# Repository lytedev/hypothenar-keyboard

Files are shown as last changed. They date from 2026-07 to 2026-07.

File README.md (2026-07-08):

# Hypothenar PCB

The v1 redesign — chip-direct nRF52840 module + I/O expanders, designed
for JLCPCB PCBA assembly. See `docs/v1-design.md` (in the repo root) for
architectural decisions and BOM rationale.

This directory is a work-in-progress. The PCB hasn't been drawn yet.

## Repositories

- **Primary**: <https://git.lyte.dev/lytedev/hypothenar-keyboard>
- **Mirror (GitHub)**: <https://github.com/lytedev/hypothenar-keyboard>
- **Sibling model**: [thenar](https://git.lyte.dev/lytedev/thenar-keyboard) — the hand-solderable original this design derives from ([GitHub mirror](https://github.com/lytedev/thenar-keyboard))

## What's here

- **`ref-designguide-schematic/`** — vendored copy of
  `ebastler/zmk-designguide` (CERN-OHL-P licensed). A reference schematic
  showing tested wireless-keyboard topologies: USB-C + ESD, TP4056 charge
  IC, XC6206 LDO, three different nRF52840 module options. This is our
  primary reference for the power tree and MCU section. Open
  `ref-designguide-schematic/designguide-schematic.kicad_sch` in KiCad
  to view.

- **`lib/kleeb/`** — vendored MIT-licensed KiCad library from
  `crides/kleeb`. The only public source of the **MS88SF3 nRF52840
  module footprint + symbol** (in `lib/kleeb/mcu.pretty/ms88sf3.kicad_mod`
  and the `mcu.kicad_sym` symbol library). Add this to KiCad's path when
  drawing the schematic.

- **`lib/marbastlib/`** — CERN-OHL-P keyboard-focused KiCad library by
  ebastler. Used by zmk-designguide. Contains symbols + footprints for
  TP4056, XC6206, USB-C connectors, etc.

3D models from both libraries are stripped (~88 MB saved). Re-fetch the
original repos if you want 3D viewer support.

## Project skeleton

Two KiCad projects ready to open:

```
kicad/hypothenar-left/
  hypothenar-left.kicad_pro    # start with: nix develop -c kicad
  hypothenar-left.kicad_sch    # currently == designguide schematic (verbatim copy)
  hypothenar-left.kicad_pcb    # empty, will populate from netlist later
  sym-lib-table               # project-local symbol library wiring
  fp-lib-table                # project-local footprint library wiring

kicad/hypothenar-right/
  hypothenar-right.{kicad_pro,kicad_sch,kicad_pcb,sym-lib-table,fp-lib-table}
```

Open either project file (`.kicad_pro`) in KiCad and the kleeb +
marbastlib libraries are wired up automatically — search the symbol
browser for `MS88SF3`, `TP4056`, `XC6206`, `USB_C` etc. and they're all
present.

## Roadmap

1. **Prune the designguide schematic** to just what we want:
   - Keep: USB-C input + ESD, TP4056 charge IC, XC6206 LDO, one MCU
     module slot, Vsense divider (for battery reporting)
   - Delete: the other two MCU modules (Holyiot and Moko — we use the
     third slot for our MS88SF3), the alternative BQ24075 charge IC,
     the LED underglow circuit, the battery protection (DW01A/FS8205)
     — optional, depends on whether we want belt-and-suspenders
   - Replace: the Ebyte E73 module footprint slot with MS88SF3
   - Save. ERC should drop from 409 to <50.

2. **Add the MCP23017 section** (not in designguide):
   - Two MCP23017 ICs per half, I²C-connected to the MCU
   - Address straps for 0x20 and 0x21
   - 4.7 kΩ I²C pull-ups
   - Reset line tied to MCU GPIO
   - Reference: `SolderedElectronics/IO-expander-MCP23017-breakout-hardware-design`

3. **Add the matrix section**: 28 switches per half. With switch-per-pin
   topology, each switch has one pin → GPIO pin on one of the MCP23017s,
   other pin → GND. No diodes.
   - Will eventually come from the ergogen scaffold (regenerated for v1
     without diodes); for now stub with a placeholder.

4. **Add the rest of the per-half peripherals**: scrollwheel encoder,
   Nice!View headers, slider switch, reset button.

5. **Run ERC clean** on the schematic.

6. **Layout in KiCad**: import netlist into the `.kicad_pcb`, place
   footprints in the chip area, then bring in the ergogen scaffold
   matrix and stitch the two together.

7. **Routing**: probably mostly by hand again (autoroute will hit
   similar plateaus as rc1).

8. **Generate**: gerbers + pick-place CSV + BOM CSV → submit to JLCPCB.

## Working on this branch

`v1` is a git branch off `main`. To work on v1:

```sh
jj edit v1                                       # check out v1 branch
jj new                                           # start a new commit
# ... edit files ...
jj describe -m "v1(...): what I changed"
jj git push --bookmark v1
```

`main` continues to be the validated rc1 design.

## License notes

This repository bundles work under three licenses that are
compatible with this project's MIT licence:

- `ref-designguide-schematic/` — CERN-OHL-P v2 (`ebastler/zmk-designguide`)
- `lib/kleeb/` — MIT (`crides/kleeb`)
- `lib/marbastlib/` — CERN-OHL-P v2 (`ebastler/marbastlib`)

Both CERN-OHL-P and MIT permit redistribution + modification. Attribution
preserved by keeping each library's original LICENSE file untouched.

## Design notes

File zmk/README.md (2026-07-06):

# Hypothenar firmware

ZMK firmware for the v1 PCBA build (MS88SF3 module + 2× MCP23017 per
half over I²C, switch-per-pin, no diodes).

## Status: skeleton

This is a starting point that compiles in principle, NOT a verified
working firmware. Several pin assignments are placeholders that must
be reconciled against the final PCB:

- **MS88SF3 pad-to-nRF52840 GPIO map** — confirm against the Minew
  datasheet, then update both `hypothenar-pinctrl.dtsi` AND
  `./ergogen/config.yaml` together so wiring matches the firmware.
- **I²C addresses** — `mcp_a` at `0x20`, `mcp_b` at `0x21` matches
  the address-strap wiring in the ergogen config. If you change those,
  update `hypothenar.dts`.
- **Battery voltage divider GPIO** — `vbatt` references `&gpio0 13`;
  the actual divider pin depends on which MS88SF3 pad is used.

The first physical board will need a debug pass to verify all of the
above before this firmware works end-to-end.

## Layout

```
zmk/
├── boards/arm/hypothenar/        # Custom Zephyr board for MS88SF3
│   ├── board.cmake
│   ├── Kconfig.board
│   ├── Kconfig.defconfig
│   ├── hypothenar.dts            # MCU + I²C + MCP23017 children
│   ├── hypothenar-pinctrl.dtsi   # Pin selections
│   ├── hypothenar.yaml           # Board metadata
│   └── hypothenar_defconfig
├── boards/shields/hypothenar/    # Keyboard shield
│   ├── Kconfig.shield
│   ├── Kconfig.defconfig
│   ├── hypothenar.dtsi           # kscan + transform + encoder
│   ├── hypothenar-layouts.dtsi   # Physical positions for Studio
│   ├── hypothenar_left.overlay   # Left half input-gpios list
│   ├── hypothenar_right.overlay  # Right half input-gpios list
│   └── hypothenar.keymap         # Default keymap
├── build.yaml
└── west.yml
```

## Build

```bash
# All-in-one (firmware + flash helper):
nix build .#firmware
nix run .#flash -- left
nix run .#flash -- right

# Or just one half:
nix build .#firmware-left
nix build .#firmware-right
```

The first build fetches Zephyr deps and fails with a hash mismatch.
Copy the hash from the failure message into `flake.nix` (the
`v1-firmware`'s `zephyrDepsHash`) and rebuild.

## Topology notes

Why switch-per-pin (no matrix, no diodes):

- 2× MCP23017 per half give 32 GPIOs; we use 28 of them.
- Each switch shorts a single MCP23017 pin to GND when pressed; the
  driver's internal pull-up keeps the line high otherwise.
- ZMK's `zmk,kscan-gpio-direct` driver polls the expanders over I²C.
- No charlieplexing, no row/column matrix, no diodes — simplest
  electrical topology, but the per-switch I/O cost is higher (32 pins
  vs ~12 for a traditional matrix).

Why this works on a battery-powered keyboard:

- MCP23017 quiescent current is ~1 µA, negligible vs the BLE radio.
- I²C bus is only polled when a switch state changes (interrupt-
  driven) — the MCP23017 INT pin can wake the MCU from sleep.

Caveat (future work): the current shield reads the expanders by
polling, not via the MCP23017's interrupt pin. For battery life that
matters; wire `INTA`/`INTB` of each expander to an MCU GPIO and add
an interrupt binding to the kscan node. See ZMK's docs on
`gpio-input-bind` for the pattern.

## ZMK Studio support

`hypothenar-layouts.dtsi` defines the physical layout for ZMK Studio so
you get a keymap visualizer. Positions come from the rc1 layout (same
key geometry) — verify the v1 PCB outline hasn't drifted before you
trust the visualization.

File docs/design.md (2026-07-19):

# Hypothenar design notes

This branch (`v1`) is a redesign of the prototype (rc1, on `main`) for
**pick-and-place assembly via JLCPCB**. The user-visible changes:

- **No Nice!Nano module** — discrete nRF52840 chip on the main PCB.
- **No diodes** — 2× MCP23017 I²C I/O expanders per half, switch-per-pin
  topology (each key wired directly to one expander GPIO).
- **Most components placed by JLCPCB PCBA**, only through-hole / mechanical
  parts (switches, hotswaps, encoder, slider, reset, battery wires)
  hand-soldered.

rc1 (current `main`) stays as the validated prototype reference.

## Architecture choices

### Drop reversibility — two separate PCB designs

rc1 used the corax-style reversible PCB (one design, flipped for the
other half, with jumpers selecting per-side wiring). That made sense
for hand-soldering: one PCB SKU, user solders the appropriate jumpers.

For v1 (PCBA), reversibility becomes a tax:

- JLCPCB places all populated footprints either way — paying for
  duplicate footprints or jumper bridges is wasted money.
- The schematic complexity (jumpers around the MCU, display, encoder)
  multiplies with each chip we add. Discrete nRF52840 + 2× MCP23017
  + USB-C + charge IC means a *lot* of new jumpers to design around.
- We can't even verify a reversible v1 design without spending the
  PCBA money up front.

**Plan: two PCB layouts emitted from one ergogen config.** Ergogen's
built-in `mirror` directive handles the geometry; we get `hypothenar-left`
and `hypothenar-right` as independent KiCad files. Each gets:

- Components placed for its specific half (MCU on the inner edge, etc.)
- Pure single-side routing (no mirror copper)
- Its own gerber + PCBA order at JLCPCB

Cost delta: separate designs are ~$50-80 more for the first PCBA run
(two design setups vs one), but save iteration time and unlock smaller
per-half boards. Net win after the first revision.

### MCU: MS88SF3 nRF52840 module (not bare chip)

**Revised from bare chip.** Use the Minew **MS88SF3-nRF52840** module
(LCSC `C20416747`, Extended). It's the nRF52840 + 32 MHz crystal +
32.768 kHz crystal + antenna + matching network + decoupling network
all in one pre-certified SMD package.

Why pick the module:

- **Same chip, same power**: ~1.5 µA System OFF, identical to bare
  nRF52840. ZMK upstream supports it as `nice_nano` or similar board.
- **Lower BOM complexity**: replaces ~10-15 discrete parts (two
  crystals, four crystal caps, RF matching components, antenna, two
  DCDC inductors).
- **Lower Extended-fee burden**: one Extended setup instead of
  separate fees for the nRF52840, antenna, and assorted RF passives.
- **Pre-certified for BLE**: saves the FCC certification work if this
  ever goes commercial. (Doesn't affect a personal-use build, but
  removes a future barrier.)
- **De-risked RF**: the hardest design risk in v1 was getting the
  antenna match and crystal layout right. The module eliminates both.

Trade-offs:
- Physical: ~18×10 mm vs the bare chip's 6×6 mm. Plenty of board space
  for our purpose.
- Slightly higher per-unit cost ($1-3) than the bare chip — paid back
  by the BOM/setup-fee savings.

No discrete crystals, no discrete antenna, no DCDC inductors. The
module exposes the nRF52840 GPIO pins as castellated edge pads.

### I/O expanders: 2× MCP23017 per half

- LCSC: **CONFLICT — resolve before ordering.** This line says `C9678`
  (Basic); the PCBA BOM table below says `C47023` (Extended). They
  disagree on both the part number and the JLC tier (which affects
  setup-fee cost). Verify the actual in-stock MCP23017-E/SO on LCSC and
  make both references match. 16 GPIOs each, 32 total per half, 28 used
  for keys + 4 spare.
- I²C address strap: 3 address pins → 8 possible addresses per bus.
  Use 2 different addresses for the 2 expanders. Both halves use the
  same addressing since the MCU is local to each half.
- Pull-up resistors: 4.7 kΩ on SDA/SCL.
- Reset: tie `RESET` to MCU GPIO so MCU can reset the expanders on
  boot.

**Why MCP23017 over PCA9555A**: PCA9555A's headline advantage is
~40 nA standby current vs MCP23017's ~1 µA. On a 110 mAh / 3.7 V
battery, 1 µA would take 12.5 years to drain — utterly negligible
compared to the BLE radio's bursty mA draws and the MCU's own
3-5 µA sleep current. MCP23017 has wider community use in the ZMK
ecosystem and better Zephyr driver support, so it's the safer pick.

### USB-C: standard 24-pin receptacle

- LCSC: `C165948` (Korean Hroparts; common JLC-stocked USB-C).
- ESD protection: USBLC6-2SC6 (`C7519`) for D+/D-.
- 5.1 kΩ resistors on CC1/CC2 for USB-C pull-down (signals "I'm a UFP
  needing power").

### Power path

- **Battery in**: LiPo 3.7V nominal, same `301230` as rc1.
- **Charge IC**: **TP4056** (LCSC `C382139`, Extended) — 100-1000 mA
  programmable charge, single-cell. Functionally equivalent to
  MCP73831 (which we'd otherwise use), cheaper. Set charge current to
  ~100 mA via 12 kΩ on the PROG pin (good rate for our 110 mAh
  battery; faster damages cell life).
- **Regulation**: Nordic nRF52840 can run directly from LiPo voltage
  via its built-in DCDC (1.7–5.5 V input range). No boost/buck needed
  for the MCU itself.
- **3.3V rail** for MCP23017 + Nice!View: **XC6206P332MR** LDO
  (`C5446`, **Basic tier**) fed from battery. 1-3 µA quiescent current
  (~10× lower than TLV70233's 31 µA — meaningful on a 110 mAh battery).
  Saves the Extended setup fee.
- **Slider switch**: Same C128955 cuts the battery feed to charge+MCU.
- **Charge LED**: optional, 1× 0603 LED + 1 kΩ resistor wired to
  MCP73831's STAT pin.

### SWD programming header

- **5 pads** on the down-side near the MCU: SWDIO, SWCLK, RST, GND, 3V3.
- 2.54 mm spacing in a single row, exposed copper (no header pins
  installed by default — clip-on or pogo probe).
- Used once per board to flash the Adafruit nRF52 bootloader. After
  that, USB drag-drop works exactly like the Nice!Nano.

### Bootloader flashing strategy

**Primary plan: JLCPCB Component Programming service**

JLCPCB will flash a `.hex` to the nRF52840 as part of PCBA. For our
2-board run that's ~$15-30 total: $8-25 setup + $0.50-1.50 per board.
Cheaper than buying our own programmer and saves the manual SWD step.

What we supply: Adafruit nRF52 bootloader hex from
<https://github.com/adafruit/Adafruit_nRF52_Bootloader> (use the
`nice_nano_v2` build — same chip layout from ZMK's perspective).

After the one-time bootloader flash, USB drag-drop works exactly like
the Nice!Nano: double-tap reset to enter bootloader, drop `.uf2` on
the mass-storage device.

**Fallback: DIY SWD via Pi Pico (`picoprobe`)**

Still expose the 5-pin SWD pads on the PCB so you can recover bricked
boards or reflash without re-ordering. With a Pi Pico flashed as
picoprobe (~$5):

```
openocd -f interface/cmsis-dap.cfg -f target/nrf52.cfg \
  -c "program adafruit_nrf52_bootloader.hex verify reset exit"
```

## ZMK shield changes

The shield needs a custom board definition (`nice_nano` board no longer
applies). Path: create `config/boards/arm/hypothenar/` as a custom Zephyr
board, then the shield references it. Includes:

- `hypothenar.dts` — MCU + power + connectivity (chosen flash partitions,
  USB, I²C, BLE)
- `hypothenar_defconfig` — Kconfig for the board
- `Kconfig.board` — board declaration
- `board.cmake` — flash/debug command wiring

The kscan changes from `kscan-gpio-matrix` to **`zmk,kscan-gpio-direct`**
with all 28 GPIOs listed explicitly (each one is a switch).

The I/O expanders need a Zephyr driver — `MCP230XX` (built into Zephyr).
Devicetree binding: declare each as an `i2c-bus` device, configure pin
modes via the driver. Then `gpio-keys` or `kscan-gpio-direct` references
the expander's GPIO controller via phandles.

## BOM at LCSC (PCBA-ready)

**Verified against JLCPCB's parts catalogue 2026-05-18.** The IC-heavy
parts of this BOM are all **Extended tier** — JLCPCB doesn't stock
keyboard-specific MCUs and ESD/USB-C/charge ICs as Basic. Expect ~$24
in one-time Extended setup fees on first order; subsequent orders
using the same parts are free.

Per half (multiply ×2 for the keyboard total). "B" = Basic, "E" = Extended.

| Designator | Part | LCSC | Tier | Notes |
|---|---|---|---|---|
| U1 | MS88SF3 nRF52840 module | **C20416747** | E | Pre-certified; includes antenna, crystals, RF matching, DCDC inductors |
| U2, U3 | MCP23017-E/SO I/O expander | C47023 | E | SOIC-28 (SOP variant) |
| U4 | TP4056 LiPo charge IC | **C382139** | E | Programmable charge current via PROG resistor |
| U5 | XC6206P332MR 3.3 V LDO | **C5446** | **B** | 1-3 µA Iq; replaces TLV70233 — Basic tier, biggest cost+power win |
| U6 | USBLC6-2SC6 USB ESD | C7519 | E | Optional — nRF52840 has integrated USB ESD diodes. Skip if BOM cost matters more than belt-and-suspenders. |
| J1 | TYPE-C-31-M-12 USB-C receptacle | C165948 | E | Hroparts |
| C1 | 4.7 µF X5R 0603 cap | C19666 | B | Bulk decoupling |
| C2–C8 | 100 nF X7R 0603 cap | C14663 | B | Local decoupling (one per IC + USB-C + battery) |
| C9, C10 | 10 µF X5R 0603 cap | (TBD) | B | Battery bulk + charge IC |
| R1, R2 | 4.7 kΩ 0603 | C23162 | B | I²C pull-ups |
| R3, R4 | 5.1 kΩ 0603 | C23186 | B | USB-C CC pull-downs |
| R5 | 12 kΩ 0603 | C25744 | B | TP4056 PROG (sets 100 mA charge) |
| R6, R7 | 1 kΩ 0603 | C21190 | B | Various |
| R8, R9 | 100 kΩ 0603 | C25803 | B | Reset pull-ups |
| D1 | 0805 red LED (status/charge) | C84256 | B | Connected to TP4056 STAT pins |

**Removed from BOM** (handled inside the MS88SF3 module): bare
nRF52840, 32 MHz crystal, 32.768 kHz crystal, four 22 pF crystal caps,
two 10 µH DCDC inductors, chip antenna. That's ~7 fewer parts to place
and ~3 fewer Extended setup fees.

**Verification corrections from my first pass** (in case I need to
re-do this with similar parts): all the original C-numbers I cited for
ICs were wrong — they pointed at unrelated resistors/ADCs/etc. The
numbers above are validated against JLCPCB's actual catalogue.

Through-hole / hand-soldered (unchanged from rc1):
- 28× Kailh Choc hotswap sockets (C5333465)
- 1× EVQWGD001 encoder
- 1× C128955 slider switch
- 1× 2-pin tactile reset
- 1× 5-pin Nice!View header (if displaying)
- 2× battery solder pads

**Rough cost per half (post-optimization)**: ~$10-18 in components +
Extended setup fee (~$15 one-time across the BOM thanks to the LDO
swap + module consolidation; ~$9 savings vs the unoptimized BOM) +
~$10-15 PCB + ~$25-40 PCBA labour. So roughly **$45-75 per half** for
the assembled board, plus the unchanged through-hole BOM.

Two designs (left + right) in the same JLCPCB order share the Extended
fees: total project cost roughly **$90-150** for both halves on first
order, ~$55-90 per pair on revisions.

Savings tally vs the original BOM:
- XC6206 LDO: -$3 Extended fee + -$0.17 piece price + ~10× lower Iq
- MS88SF3 module: -3 Extended fees (crystals, antenna, nRF52840) + -7
  parts to place + zero RF design risk
- TP4056 charge IC: -$0.28 piece price
- Skip USBLC6 (optional): -$3 Extended fee + -$0.25 piece price

If we skip USBLC6 (the nRF52840 has integrated USB ESD diodes), total
Extended fees drop to ~$12 and per-half BOM cost to ~$8-15.

## Layout/routing risks (in roughly increasing order of risk)

1. **Power decoupling placement** — well-known recipe in the nRF52840
   datasheet. Follow Nordic's reference layout.
2. **I²C bus routing** — keep traces short, 4.7 kΩ pull-ups, both
   expanders on same bus is fine.
3. **USB-C signal integrity** — D+/D- should be ~90 Ω differential. At
   USB 2.0 speeds and our short trace lengths it's forgiving.
4. **32 MHz crystal layout** — Nordic has strict guidelines (ground
   guard ring, exact load caps). Get this wrong and BLE may not start.
5. **2.45 GHz antenna match** — even with a chip antenna, the feed
   trace needs a ground-keepout zone of ~5×8 mm. Get this wrong and
   range/reliability suffers.
6. **DCDC inductor layout** — physically close to nRF52840's DCC pins
   with a short ground return.

## Roadmap

- [ ] Architectural spike: confirm I²C-based I/O expanders work with ZMK
      via `MCP230XX` driver (research existing builds).
- [ ] Schematic in KiCad (NOT ergogen — ergogen doesn't do schematics,
      and we need one for proper review).
- [ ] Footprint set: vet ceoloide / infused-kim libraries; supplement
      with custom footprints where needed.
- [ ] Ergogen config that emits the matrix layout + key positions, then
      manually overlay the chip / power / USB area in KiCad on top of
      the ergogen scaffold.
- [ ] First-pass PCB layout in KiCad. Order of design: place MCU + RF
      first, then power, then I²C bus, then key matrix wiring.
- [ ] Pick-place + BOM files via `kicad-cli pcb export pos --format csv`
      and `kicad-cli sch export bom`.
- [ ] Test PCBA order: 5 boards, 1 fully assembled, 4 bare for spares /
      iteration.

## Reference designs

Identified through targeted search; each contributes a different
piece of the v1 design.

### Primary reference: `Ladniy/jiran-ble-lite`

<https://github.com/Ladniy/jiran-ble-lite>

- **License**: CERN-OHL-P v2.0 (permissive open hardware — fork-friendly)
- **Architecture**: Holyiot-18010 nRF52840 module (different module
  than our MS88SF3 but same architectural approach — pre-certified RF
  module instead of bare chip), split ergo, traditional matrix
- **KiCad source**: confirmed `.kicad_sch` / `.kicad_pcb` / `.kicad_pro`
  in `pcb/jiran-ble-lite/`, with separate left/right schematic files
- **Maturity**: 300+ commits, v1.1.3 (Oct 2023)
- **What we take**: split-half mechanics, power tree topology, USB-C +
  charge IC layout, KiCad project structure
- **What we replace**: Holyiot footprint → MS88SF3, the matrix
  section (their diodes → our MCP23017 expanders)

### Symbol/footprint source: `crides/kleeb`

<https://github.com/crides/kleeb>

- MIT-licensed KiCad 6 symbol + footprint library
- **The only place I found with MS88SF3 symbols** (`ms88sf3-nrf52840`
  and `ms88sf3-nrf52840-split`)
- Pull symbol + footprint directly from this library

### Power-tree reference: `ebastler/zmk-designguide`

<https://github.com/ebastler/zmk-designguide>

- Reference schematics for three nRF52840 modules (including Holyiot)
- Power-tree patterns (LDO sizing, VDDH handling for nRF52840 DCDC)
- Cross-reference for ZMK board file structure
- Companion library: `ebastler/marbastlib` (symbols + footprints)

### JLCPCB PCBA-feasibility reference: `ebastler/cornholius`

<https://github.com/ebastler/cornholius>

- License: CC BY-NC-SA 4.0 (**non-commercial only**, fine for personal
  use but be aware if you ever sell)
- **Gerbers only** (no `.kicad_sch` — can't fork the layout) but the
  repo includes a BOM proven against JLCPCB's economic/standard PCBA
  parts list
- Use as a sanity check: "are the parts we picked actually
  PCBA-assembled in a known-working design?"

### MCP23017 reference: `SolderedElectronics/IO-expander-MCP23017-breakout-hardware-design`

- Reference schematic for the MCP23017 section (TAPR OHL licence)
- Standard configuration: I²C pull-ups, address straps, reset
- Combined with `ZMK PR #1567` (MCP23017 driver) for the firmware
  side

## Concrete forking plan

1. **Fork `jiran-ble-lite`** into our `v1` directory as the starting
   PCB project
2. **Swap the MCU footprint**: Holyiot 18010 → MS88SF3, using kleeb's
   library
3. **Adapt the power tree**: TLV70233 → XC6206 (per our BOM
   optimisation), MCP73831 → TP4056
4. **Add the MCP23017 section** (not present in jiran-ble-lite),
   using SolderedElectronics' reference + ZMK driver docs
5. **Replace the matrix** with our ergogen-scaffold output (modify
   the ergogen config to output two-half / non-reversible layouts)
6. **Test the BOM** against cornholius's JLCPCB-PCBA patterns
7. **Generate the gerbers + pick-place + BOM CSV**, submit to JLCPCB
   for first PCBA order

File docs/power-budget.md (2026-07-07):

# Power budget & battery-life estimate

Analytical estimate for the hypothenar's 110 mAh (301230) LiPo, built
from datasheet figures and ZMK community baselines. This is a
**prediction with error bars, not a measurement** — the free empirical
check is logging ZMK's BLE battery telemetry on real hardware over a
week (see "Validating" below).

Numbers marked *typ* are typical datasheet values; real silicon and
temperature spread them. Where a figure comes from community
measurement rather than a datasheet it is marked *(community)*.

## Always-on floor (everything idle, radio connected)

| Draw | Current (typ) | Source |
|---|---|---|
| nRF52840, BLE connected idle (30 ms conn. interval) | ~50–100 µA | *(community)* — [ZMK power profiler](https://zmk.dev/power-profiler) baseline for nice!nano-class nRF52840 boards |
| XC6206P332MR LDO quiescent | 1–3 µA | [Torex XC6206 datasheet](https://www.torexsemi.com/file/xc6206/XC6206.pdf), Iq typ 1 µA |
| MCP23017 standby × 2 | ~2 µA | [MCP23017 datasheet](https://ww1.microchip.com/downloads/en/DeviceDoc/20001952C.pdf), Icc standby 1 µA max each |
| TP4056 battery reverse leakage (no USB) | ~2 µA | TP4056 datasheet (NanJing TopPower; no stable URL — value from the commonly distributed datasheet, flagging accordingly) |
| Battery ADC divider | ~0 (switched) | Divider is behind the P0.05 enable GPIO; conducts only during samples |
| **Idle total** | **~60–110 µA** | |

## Deep sleep (ZMK soft-off / System OFF after idle timeout)

| Draw | Current (typ) | Source |
|---|---|---|
| nRF52840 System OFF, full RAM retention | ~1.5–3 µA | Nordic nRF52840 datasheet, "Current consumption" (docs.nordicsemi.com) |
| LDO + MCP23017 ×2 + TP4056 | ~5 µA | as above — these stay powered |
| **Sleep total** | **~7 µA** | |

Enabled via `CONFIG_ZMK_SLEEP=y` + 15-minute idle timeout in zmk/hypothenar.conf.

## The term that dominates: switch scanning

This design has no matrix — 28 switches sit behind two I²C expanders,
and `zmk,kscan-gpio-direct` reads them through the Zephyr MCP23xxx
driver. Two very different worlds:

- **Interrupt mode (what we wired)**: INTA of each expander → MCU GPIO
  (P0.30 / P0.02). Idle cost ≈ 0; each keypress costs a sub-ms I²C
  burst. At heavy typing (~5 keys/s) the scanning term averages
  **< 10 µA**. Rounding error.
- **Polling fallback (if interrupts were broken)**: reading both
  expanders every ~10 ms keeps the MCU + I²C bus duty-cycled
  continuously — order **300–500 µA average**, i.e. the battery dies
  in **~9–14 days** regardless of everything else. This is why the
  INT traces exist.

## Duty-cycle scenarios (interrupt mode)

Assume 16 h/day awake-and-connected, 8 h/day deep sleep:

| | mAh/day | 110 mAh lasts |
|---|---|---|
| Optimistic (60 µA idle, sleep works) | ~1.0 | **~3.5 months** |
| Central (90 µA idle) | ~1.5 | **~2.5 months** |
| Pessimistic (110 µA + no deep sleep, 24 h connected) | ~2.6 | **~6 weeks** |
| Polling fallback (broken interrupts) | ~8–12 | **~9–14 days** |
| Realistic 8 h/day active use + 15 h deep sleep | ~1.3 | **~2.5–3 months** |

Typing adds surprisingly little: connected-idle already pays the BLE
keep-alive tax, and active keystrokes only add ~50–150 µA *while
typing* (~5 µC per radio event at 10–20 events/s — estimate from BLE
event-charge math; the ZMK power profiler models the same). Battery
life is governed by **hours connected**, not keystrokes — a real
workday with aggressive sleep matches the 16 h-connected scenario.

The right half (peripheral) sits in the same band — its BLE peripheral
link to the central costs about the same as the central's dual role.

Adds if fitted: nice!view display ≈ +2–15 µA (Sharp memory LCD;
negligible). A rest-closed encoder contact against an internal ~13 kΩ
pull-up would cost ~250 µA — **verify at bring-up that the EVQWGD001's
detent-rest position leaves both contacts open**; if not, the pulls
need to be external and larger.

## Bottom line

**~2–3.5 months** per charge if the interrupt path works and deep
sleep is enabled; **~9–14 days** if scanning silently degrades to
polling. The gap between those two numbers is the entire reason the
INTA traces are on the board, and it is also the cheapest possible
test instrument: battery life in *weeks* = interrupts broken, in
*months* = working — readable from ZMK's own battery telemetry with
no bench equipment.

## Actions this analysis produced

- [x] Wire MCP23017 INTA → MCU (P0.30/P0.02) — done
- [x] Enable `CONFIG_ZMK_SLEEP=y` (+ idle timeout) — zmk/hypothenar.conf
- [ ] At bring-up: verify encoder rest-state contacts are open
- [ ] Validate: log BLE-reported battery % over a week of real use
      (upower on the connected host, 15-min samples); slope → real
      battery life. No PPK2 required.

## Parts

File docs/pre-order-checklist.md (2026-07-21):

# Pre-order checklist — the gate to a fab-ready PCBA

**Verdict as of this pass: NOT ready to order.** This board is a JLCPCB
pick-and-place run — SMD parts are baked in and cannot be reworked — and
it has **no schematic / no ERC**, so the ergogen nets are the only
netlist. This checklist is the gate: the board is "known ready to order"
only when every 🔴 item below is done and both halves pass a clean DRC.

Derived from the 2026-07 validation pass (netlist ERC cross-read +
`kicad-cli` DRC on `routed/keyboard-left.kicad_pcb` + BOM review).

> **⚠️ ARCHITECTURE CHANGED (2026-07): I2C expanders → diode matrix.**
> The 2× MCP23017 + I2C are gone; switches now scan as a direct diode
> matrix off the MS88SF3 (ergogen done + validated). This makes some
> items below stale — the routed boards are now doubly-outdated (the old
> layout AND the old architecture), so **both halves are a fresh route
> from the new scaffold.** Two new must-do items:
> - **Firmware kscan conversion** ✅ DONE — swapped to
>   `zmk,kscan-gpio-matrix` (6×12 transform, `diode-direction=col2row`) on
>   the verified pins; i2c/mcp nodes removed; encoder rotation fixed to
>   MCU P0.29/P0.28 (was the old mcp bug). **Builds clean both halves**
>   (`nix build .#firmware`). Two follow-ups, neither blocking:
>   *(a)* encoder **button** (ENC_SW=P0.13) still not scanned — it wasn't
>   before either; add via kscan-composite when wanted. *(b)* right-half
>   **column order** on the mirrored PCB is a bring-up-verify item (reverse
>   col-gpios in the right overlay if reversed — the thenar's bug class).
> - **BOM update** (part of item 4): remove the 2× MCP23017 + I2C
>   pull-ups/decoupling; add 28 diodes/half (Basic, e.g. 1N4148W / SOD-123)
>   — net *savings* (drops ~2 Extended setup fees).

---

## Done in this pass (source fixes)

- ✅ **MS88SF3 pad map datasheet-verified** (the foundational gate) — all
  assigned pads correct against Minew rev-K; see item 1 below.
- ✅ **Battery-sense divider resistors added** — R9 (820k, VBAT→BATT_ADC)
  + R10 (2.0M, BATT_ADC→BATT_ADC_EN), matching the firmware's divider
  (`output-ohms=2.0M`, `full-ohms=2.82M`). `BATT_ADC` was a floating
  single-pad net; now connected. *Verify R9/R10 placement on regen —
  shifts are near the MCU decoupling and may need nudging (a re-route is
  required anyway).*
- ✅ **Stale pin comment in `hypothenar.dts` deleted** — it listed
  `P14=USB_DP / P20=I2C_SCL / …`, which was wrong and would have
  sabotaged the datasheet cross-check.
- ✅ **BOM MCP23017 conflict flagged** — `C9678`/Basic (body) vs
  `C47023`/Extended (BOM table). Must be resolved (see 🔴 below).

## Verified GOOD (don't re-litigate)

- I²C bus: SDA=P0.26 / SCL=P0.27 match firmware; 4.7k pull-ups present;
  two MCP23017s at distinct 0x20 / 0x21.
- **Both INTA interrupt lines** wired and match firmware (P0.30 / P0.02)
  — the weeks-vs-months power factor is correct.
- Power tree: VBAT → TP4056 BAT / LDO VIN / MCU VDDH; PROG 12k → ~100 mA;
  CC pull-downs present; no power-net shorts.

---

## 🔴 Blocking requirements — must all be done before ordering

### 1. GATE — datasheet-verify the MS88SF3 pad map ✅ DONE (2026-07)
Cross-checked every assigned pad against the **Minew MS88SF3 rev-K
datasheet** (Datasheet_K_EN, §3 Pin Description diagram). **All correct,
pad-for-pad** — GND 1/18/34, VDD 31, VDDH 32, VBUS 35, D- 36, D+ 37,
SWDIO 49, SWCLK 50, and every GPIO (P9=P0.02, P10=P0.29, P11=P0.28,
P12=P0.30, P13=P0.31, P14=P0.27, P15=P0.05, P16=P0.04/AIN2, P17=P0.26,
P28=P0.18, P41=P0.17, P44=P0.20, P45=P0.22). Pads 33=DCCH / 51=RF
correctly NC. `config.yaml` + `hypothenar.dts` status updated. **Gate
cleared** — the netlist rests on a correct foundation.

### 2. Add the SWD + debug/expansion breakout header ✅ DONE (source)
`ergogen/footprints/breakout.js` + a `breakout` entry now expose **SWD
(SWDIO/SWCLK/RST) + power (3V3/GND/VBAT) + all 34 free nRF GPIOs** on a
2×20 header, auto-wired via net defaults (the 34 free MS88SF3 pads carry
`GP_*` nets that land on the header). Validated: ergogen regenerates,
KiCad loads it (J1), each `GP_*` net connects MCU-pad↔header-pad. This
kills the unprogrammable-brick blocker. **Remaining (yours, in KiCad):**
the 2×20 header is ~50×5 mm and a placeholder position — **relocate it to
open board space and trim pads/rows** to what fits ("start Max, shrink").
Its routing folds into item 3.

Original context (the matrix is entirely on the I²C expanders, so most
GPIOs are free):
- **SWD/bring-up (required):** SWDIO, SWCLK, RESET, GND, 3V3 (VDD_MCU).
- **Power taps:** VBAT, VBUS (optional).
- **Free GPIO expansion:** the pad map is now verified, so here is the
  full free-GPIO list (unused, real nRF52840 GPIOs). Pick as many as the
  header size allows:
  - **P0 free (18):** P0.00·pad25, P0.01·pad24, **P0.03·pad6 (AIN1 — the
    one free analog-capable pin)**, P0.06·21, P0.07·20, P0.08·27,
    P0.09·55, P0.10·56, P0.11·23, P0.13·39, P0.14·30, P0.15·40, P0.16·29,
    P0.19·38, P0.21·42, P0.23·43, P0.24·46, P0.25·48
  - **P1 free (16):** P1.00·47, P1.01·59, P1.02·52, P1.03·60, P1.04·53,
    P1.05·58, P1.06·54, P1.07·57, P1.08·22, P1.09·26, P1.10·4, P1.11·2,
    P1.12·3, P1.13·7, P1.14·5, P1.15·8
  - ~34 free GPIOs total — the matrix is entirely on the I²C expanders,
    so the MCU is wide open. Note P0.00/P0.01 (pads 24/25) are the LFXO
    pins; the module has no 32 kHz crystal (ZMK uses internal RC), so
    they're usable as GPIO — but if you ever want a real 32 kHz crystal,
    reserve them.
- Needs a header/test-pad footprint (model on `battery_pads.js`) + a
  placement on the board. *Can be implemented here — say which/how many
  free pins to break out and I'll add the footprint + nets.*

### 3. Finish routing — per half, to a clean DRC
The left half is a ~95% freerouting **baseline**, not a finished board;
the right half isn't routed at all.
- **Left (`routed/keyboard-left.kicad_pcb`):** fix **4 USB shorts**
  (`USB_DP/USB_DM/VBUS/GND` ring at the connector) and route the **8
  opens** (incl. `USB_DP` pad A6, thumb switch S27, several GND pads).
- **Right half:** route it (mirror/second layout) from the updated
  scaffold.
- Re-run `kicad-cli pcb drc` on **each** half → **0 errors, 0 unconnected
  items** is the gate (silk/text warnings are fine; relax copper-to-edge
  to JLC's 0.3 mm min or nudge the 5 offenders).

### 4. Footprints are hand-solder heritage — adapt them for pick-and-place
These footprints came from the thenar (hand-soldered, reversible board)
and haven't been adapted to a single-sided PnP run. Three findings, all
caught while eyeballing the board in KiCad:

- ✅ **USBLC6 pads were shorted** — 1.2 mm-tall pads on a 0.95 mm pitch
  overlapped 0.25 mm, merging pins 1-2-3 and 4-5-6 and shorting
  `USB_DP`/`GND`/`USB_DM`/`VBUS` (a dead VBUS→GND short). Width/height
  were transposed. **Fixed** → DRC shorts now zero. *(This also explains
  the 4 "freerouting" shorts we'd misdiagnosed on the routed board.)*
- ⬜ **Diodes are on the FRONT.** `diode.js` (ComboDiode) has no `side`
  param and emits pads on **both faces plus through-hole** — great for
  hand-solder flexibility, wrong for PnP. All 28 land on top, which
  would force **double-sided assembly** (a real cost adder). Needs a
  bottom-only SMD variant (drop the F.Cu SMD pads and the THT pads).
- ⬜ **CPL reports the wrong side for everything.** Footprints hardcode
  `(module … (layer F.Cu))` even when `side: B` correctly routes their
  *pads* to `B.Cu` (MS88SF3, TP4056, XC6206, USBLC6, passives). KiCad's
  CPL export reads the **footprint layer**, so JLC would be told to
  place bottom-side parts on **top** → mis-assembled board. Fix: make
  the module layer follow `${p.side}` in the affected footprints, then
  verify the CPL shows `bottom` for all SMD.

### 5. Resolve the BOM MCP23017 part number
Verify the in-stock LCSC part (`C9678` vs `C47023`) and tier, make the
`design.md` body and BOM table agree, and confirm **USBLC6** is a BOM row
(it's in the netlist but wasn't in the table rows checked).

---

## 🟡 Should-do (not strictly order-blocking)

- **Encoder is mis-wired in firmware, not hardware** — the PCB is fine
  (quadrature on MCU P0.29/P0.28, button on `mcp_b` GPA4). Firmware reads
  `mcp_b 4/5`, so as-is the encoder + its button are dead. Fix in
  firmware (no PCB change): set `hypothenar.dtsi` `a-gpios=<&gpio0 29 …>`,
  `b-gpios=<&gpio0 28 …>`, and add `mcp_b` GPA4 to the kscan + a keymap
  position for the button. Doesn't block the order.
- **USBLC6 footprint pinout** — eyeball the pad→pin map in KiCad once
  (shunt ESD on DP/DM/VBUS/GND); low risk, but unverifiable statically.
- **Charge-while-off** — the slider sits *before* the TP4056
  (`VBAT_SW → slider → VBAT → charger`), so **slider off = no charging**
  (same trap as the thenar). If you want off-but-charging, rearrange:
  cell always on the TP4056 BAT, slider as a load switch on VBAT→MCU.
  Design decision.
- **Nice!View SPI** defined in pinctrl but no `&spi0`/display node in the
  DTS — display won't drive until added (firmware-only, post-order OK).

---

## Definition of "known ready to order"

All four 🔴 done, i.e.:
1. MS88SF3 pad map datasheet-signed-off, `config.yaml` + `hypothenar.dts`
   in lockstep.
2. SWD + breakout header on the board.
3. **Both** halves route to **0 DRC errors + 0 unconnected**.
4. BOM part numbers verified in-stock, no conflicts, USBLC6 present.

Then: export gerbers + drills per half (`build-recipe.md` Stage 6–7),
upload to JLCPCB, order. The 🟡 items can trail (firmware/optional).

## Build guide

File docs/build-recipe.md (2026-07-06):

# Hypothenar build recipe

End-to-end recipe to take `./ergogen/config.yaml` from a scaffold to a
JLCPCB pick-and-place order. Read [`v1-design.md`](./v1-design.md) first
for the architecture rationale (MS88SF3 module, 2× MCP23017, MCU-on-PCB
power tree).

This is a working-style document — write down what worked, mark what
didn't, and skip steps you've already done. The `Verify` lines are
checks I (Claude) leave for myself when picking the work back up later;
treat them the same way you would.

## Tools you need

- KiCad 9 — `nix shell nixpkgs#kicad` or your system install
- ergogen 4.x — `nix shell nixpkgs#ergogen`
- freerouting v2.2.4 — built by this flake; `nix run .#freerouting -- --help`
- `nix build .#scaffold` for a fresh ergogen output

## Stage 0 — regenerate the scaffold

The scaffold is the source-of-truth for placement; if you change
`./ergogen/config.yaml`, redo it.

```bash
# Pure-nix build (cached):
nix build .#scaffold && ls result/

# Or in-place for iteration:
nix run nixpkgs#ergogen -- ./ergogen -o /tmp/hypothenar-scaffold
```

The output contains `pcbs/keyboard.kicad_pcb` (a fab-format kicad_pcb,
no traces). The flake's `v1-scaffold` derivation also upgrades it to
KiCad 9 format and writes a `.kicad_pro` next to it so the project
opens cleanly.

**Verify:**

```bash
grep '(module ' result/pcbs/keyboard.kicad_pcb \
  | awk '{print $2}' | sort | uniq -c
# Expect: 28 PG1350, 2 MCP23017, 1 each of MS88SF3, USB-C, USBLC6,
#         TP4056, XC6206, encoder, slider, reset, text, 4 Hole.
```

If a class is missing, the `pcbs.keyboard.footprints` block in
`config.yaml` references a tag that no point carries (see commit
`fix(./ergogen): scaffold places all components` — same trap).

## Stage 1 — open the project and set design rules

Open `result/pcbs/keyboard.kicad_pro` in KiCad. The scaffold is on
sheet `keyboard.kicad_pcb`; everything else (project file, schematic
stub if you want one) is up to you. We're routing-only — no schematic.

**Board stackup** (File → Board Setup → Board Stackup → Physical Stackup):
two-layer, 1.6 mm thickness, 1 oz copper. JLCPCB's default.

**Design rules** (File → Board Setup → Design Rules → Constraints):

| Setting | Value | Why |
| --- | --- | --- |
| Minimum clearance | 0.127 mm | JLCPCB 5/5 mil cheap tier. Cheaper if you go 6/6 = 0.15 mm. |
| Minimum track width | 0.127 mm | Same. |
| Minimum via size | 0.6 mm | JLCPCB minimum drill 0.3 mm; via annular ring at least 0.15 mm. |
| Minimum via drill | 0.3 mm | JLCPCB cheap tier. |
| Minimum hole-to-hole | 0.5 mm | JLCPCB requirement. |
| Copper-to-edge clearance  | 0.3 mm | Edge.Cuts safety margin. |

**Net classes** (File → Board Setup → Net Classes):

| Net class | Track width | Via dia/drill | Members |
| --- | --- | --- | --- |
| Default | 0.2 mm | 0.6 / 0.3 | everything else (signal, switch matrix) |
| Power | 0.4 mm | 0.8 / 0.4 | `VBUS`, `VBAT`, `VBAT_SW`, `VCC`, `GND` |
| USB | 0.25 mm | 0.6 / 0.3 | `USB_DP`, `USB_DM` (diff-pair-ish, see below) |

Power tracks at 0.4 mm carry ~1 A comfortably with negligible
temperature rise — well above any real load on this board.

## Stage 2 — push components to final positions

The scaffold drops every component along an arc tangent to the matrix.
That's a starting point, not a layout. Push them into the right
half-board zones:

```
+-------------------------------------+
| matrix (5x6) and thumb cluster      |
|                                     |
|  MCU              MCP_A   MCP_B    |
|  (MS88SF3)        (left)  (right)  |
|                                     |
|  USB-C (edge)     LDO    Charge IC |
|  ESD (close to USB-C)               |
+-------------------------------------+
       \---/
       slider + reset edge
```

Concrete placement rules:

1. **USB-C goes at the top edge of the board**, centered between the
   inner two columns of the matrix. Cable strain-relief is the most
   important constraint — put it at a board edge so the connector
   ground tabs can solder to a board cutout.
2. **MS88SF3 antenna keepout.** The antenna is on one short edge of
   the module (see Minew datasheet, pg. 4). Orient the module so the
   antenna edge faces *off the PCB or toward a board edge*, with no
   ground plane within 5 mm of the antenna and no copper at all
   within 2 mm. **This is the single most consequential placement
   decision** — getting it wrong tanks BLE range.
3. **MCP23017s** sit *between* the MCU and the keys they drive. MCP_A
   has the num + top row keys; MCP_B has home + bottom + mod + thumbs.
   Aim for short trace runs from each expander pin to its switch.
4. **USBLC6 ESD** sits between the USB-C connector and the MCU's USB
   pins. As close to the USB-C as practical. The two diodes inside
   only protect what's downstream of them.
5. **TP4056 charge IC + XC6206 LDO** sit next to the USB-C area. The
   LDO needs a 1 µF input cap and 1 µF output cap (the BOM has
   100 nF — add 1 µF locally during this stage, see Stage 3).
6. **Slider switch + reset button at the bottom edge** so they're
   accessible when the case is closed.

Use `Edit → Select All Footprints → Move` to grab the MCU cluster as a
group and slide it inside the board outline. The scaffold pushes it
*outside* the outline (top-right corner) because ergogen anchors are
keyed off the matrix corner; rip it inside.

**Verify:** `kicad-cli pcb export svg --output /tmp/check.svg result/...`
and visually scan for collisions / footprints outside the board edge.

## Stage 3 — schematic decoupling caps (added in PCB editor)

There's no schematic. Add the decoupling caps directly as PCB
footprints using `Place → Footprint`, pick the 0603 cap from the
KiCad library (`Capacitor_SMD:C_0603_1608Metric`), and assign nets in
the footprint properties.

Required caps (per Nordic reference):

| Designator | Value | Net (one side) | Net (other side) | Location |
| --- | --- | --- | --- | --- |
| C1 | 4.7 µF  | VBUS | GND | next to USB-C VBUS pin |
| C2 | 100 nF  | VBUS | GND | next to USB-C |
| C3 | 1 µF | VBAT | GND | TP4056 VBAT pin (BATT input bulk) |
| C4 | 1 µF | VBAT | GND | XC6206 input pin (LDO input bulk) |
| C5 | 1 µF | VCC | GND | XC6206 output pin (LDO output bulk) |
| C6 | 100 nF  | VCC | GND | MS88SF3 VDD pin (MCU decoupling) |
| C7 | 100 nF  | VCC | GND | MCP23017 #1 VDD pin |
| C8 | 100 nF  | VCC | GND | MCP23017 #2 VDD pin |

Each 100 nF cap must be **within 2 mm** of its IC's VDD pad. The 1 µF
and 4.7 µF bulk caps can be further away but should be on the same
copper pour.

Resistors (also place in PCB editor):

| Designator | Value | From | To | Notes |
| --- | --- | --- | --- | --- |
| R1 | 4.7 kΩ  | VCC | I2C_SCL | I²C pull-up |
| R2 | 4.7 kΩ  | VCC | I2C_SDA | I²C pull-up |
| R3 | 5.1 kΩ  | USB_CC1 | GND | UFP role pull-down |
| R4 | 5.1 kΩ  | USB_CC2 | GND | UFP role pull-down |
| R5 | 12 kΩ | TP_PROG | GND | sets TP4056 charge current ≈ 100 mA |
| R6 | 100 kΩ  | VCC | I2C_RESET | pull-up so MCP23017 doesn't reset spuriously |
| R7 | 100 kΩ  | VCC | RESET | MCU reset pull-up |
| R8 | 1 kΩ | CHARGE_*  | LED+ | charge-indicator LED current limit (optional) |

## Stage 4 — route the board

Two strategies. The rc1 hybrid approach (route critical nets by hand,
autoroute the rest) worked well — it produced 44 vias vs 102 starting
from autoroute-only. Repeat that here.

### 4a. Hand-route critical nets first

Do these by hand, in this order:

1. **USB-C D+ / D-**. Keep them as a tight pair (parallel, equal length
   if you can swing it). They run from USB-C through USBLC6 to the
   MCU's USB pins. The whole pair should be ≤ 30 mm total.
2. **Antenna keepout zone**. Skip if not using the bare-chip nRF52840
   — the MS88SF3's antenna is internal. But still: don't route ground
   pour inside the antenna keepout zone on the module datasheet.
3. **Crystal**. The MS88SF3 has internal crystals, nothing to route.
4. **Power tree**: USB-C VBUS → TP4056 IN → battery → slider → TP4056
   OUT → MCU VBAT input → LDO IN → LDO OUT → MCU VCC, MCP23017s. Use
   the `Power` net class so traces are 0.4 mm.
5. **I²C bus**. Two short traces (SCL, SDA) from MCU to both MCP23017
   expanders. Keep both expanders on the same bus; don't make a
   star — daisy-chain.

### 4b. Autoroute the rest with freerouting

The remaining nets are 28 switch-to-MCP23017 hookups (single-ended,
short, no constraints). Autoroute them:

```bash
# Save your in-progress PCB first.
nix run .#route -- result/pcbs/keyboard.kicad_pcb /tmp/hypothenar-routed.kicad_pcb

# Replace the working PCB with the autorouted one (after diffing!):
cp /tmp/hypothenar-routed.kicad_pcb routed/keyboard-left.kicad_pcb
```

`v1-route` runs freerouting v2.2.4 with the rc1 pass count (50) and
the freerouting config (in this repo at `scripts/freerouting.rules`).
Expected ~20 min runtime; expect ~90-95% routed. Remaining unrouted
nets are usually the I²C and power ones we already hand-routed —
verify and clean up.

**Verify** by opening the PCB in KiCad: PCB Editor → Inspect → DRC.
Fix all errors before going to gerbers.

## Stage 5 — fill GND zones

Both layers get a flood-fill GND pour. Place → Add Filled Zone →
F.Cu, net = GND, hatched fill, clearance 0.3 mm. Repeat on B.Cu.
Press B to fill.

This buys two things: shorter ground returns (every via to GND is a
direct connection to the pour, not a wire) and a slight bit of EMI
shielding.

## Stage 6 — export fabrication files

```bash
nix build .#gerbers && ls result/
# Produces gerbers + drill files + pick-place CSV + BOM CSV
```

The `v1-gerbers` derivation also runs DRC inside KiCad and fails the
build if any errors remain.

## Stage 7 — order at JLCPCB

1. Upload `result/v1-keyboard-left.zip` (gerbers + drills) to JLCPCB.
2. Quantity: 5 (cheapest tier; you'll use 1, keep spares).
3. PCBA: yes, top side, standard tier.
4. Upload `result/v1-keyboard-left-bom.csv` and
   `result/v1-keyboard-left-cpl.csv` (pick-place).
5. Add Component Programming service (one-time setup) with the
   bootloader hex from
   `https://github.com/adafruit/Adafruit_nRF52_Bootloader/releases`
   (pick the `nice_nano_v2` build).
6. Repeat for the right half.

First order pays the Extended part setup fees (~$24); subsequent
revisions are free.

## Stage 8 — receive boards, smoke test

When the boards arrive:

1. Visual inspection: no shorts on the MCU pads, USB-C aligned, no
   tombstoned passives.
2. Power-only test: plug USB-C, check VCC = 3.3 V at the MCU pin
   (probe a cap, not the pad — easier).
3. Bootloader sanity: double-tap reset, expect `NICENANO` to appear
   as a mass-storage device. If it does, JLCPCB's bootloader flash
   worked.
4. ZMK firmware: `nix run .#flash -- left` (after Stage 9).

## Stage 9 — firmware build

See [`zmk/README.md`](../zmk/README.md). The short version:

```bash
nix build .#firmware-left
nix build .#firmware-right
nix run .#flash -- left
```

## Known traps

Things I'd like future-me to remember:

- **The MCU cluster anchors outside the board outline.** Move it inside
  before routing — `config.yaml` puts it where the matrix outline ends,
  not where it'd fit on the board. The fix is in `config.yaml` not
  KiCad; eventually rewrite the anchor as relative to `matrix_inner_home`
  with a smaller shift.
- **`undefined` pad nets are silent bugs.** If a footprint param has a
  plain string default (not `{ type: 'net', value: 'X' }`), the PCB
  emits `undefined` as the net spec and KiCad refuses to load. Always
  net-type your defaults.
- **`(fp_text user "${REFERENCE}")` from KiCad is hostile to JS template
  literals.** The converter escapes those; if you copy-paste from a
  fresh kicad_mod, escape `${` to `\${` manually.
- **Tags, not zone names, in `where:`.** A `pcbs.footprints.X.where: <zone>`
  doesn't auto-match — give each zone a unique tag if you want to
  target it.

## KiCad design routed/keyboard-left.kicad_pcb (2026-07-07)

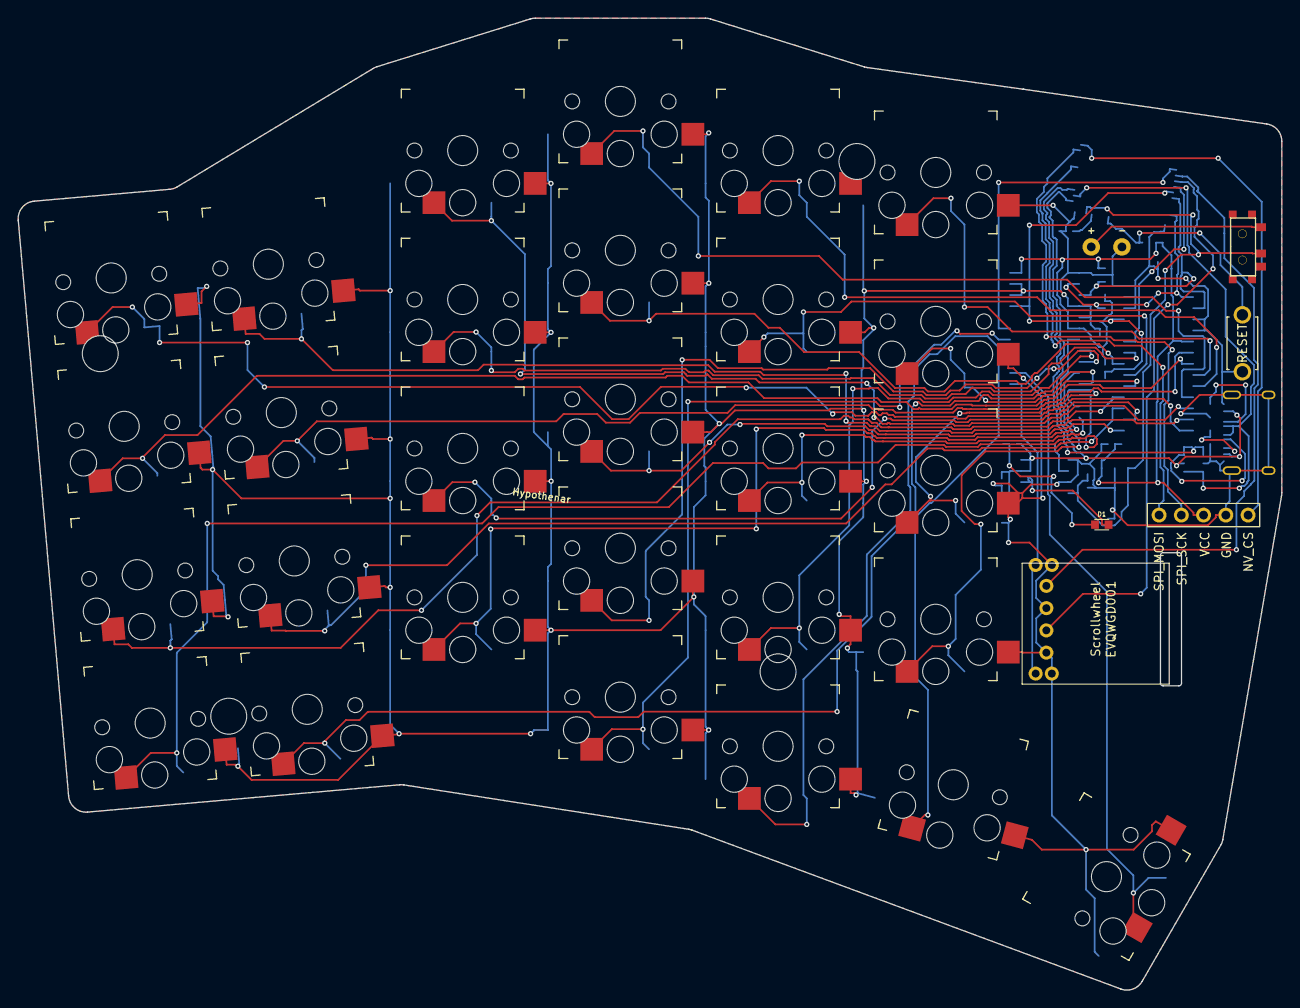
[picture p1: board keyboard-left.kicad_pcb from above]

Board: 2 copper layers, 144.2 x 110.9 mm, 60 parts (0 on the bottom side), 50 nets.

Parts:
19.051: ms88sf3
19.052, 19.053: MCP23017; MCP23017_SOIC-28W
19.054: USB_C_Receptacle_HRO_TYPE-C-31-M-12
19.055: USBLC6-2SC6; USBLC6-2SC6_SOT-23-6
19.056: TP4056; TP4056_SOP-8
19.057: XC6206P332MR; XC6206_SOT-89-3
BT1: BATTERY; battery_pads
DISP1: display_nice_view
P1: C1; passive_0603
P2: C2; passive_0603
P3: C3; passive_0603
P4: C4; passive_0603
P5: C5; passive_0603
P6: C6; passive_0603
P7: C7; passive_0603
P8: C8; passive_0603
P9: R1; passive_0603
P10: R2; passive_0603
P11: R3; passive_0603
P12: R4; passive_0603
P13: R5; passive_0603
P14: R6; passive_0603
P15: R7; passive_0603
P16: R8; passive_0603
P17: D1; passive_0603
S1, S2, S3, S4, S5, S6, S7, S8, S9, S10, S11, S12, S13, S14, S15, S16, S17, S18, S19, S20, S21, S22, S23, S24, S25, S26, S27, S28: PG1350
T1: SPDT_C128955
_1: ResetSW
_2, _3, _4, _5: Hole

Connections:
CHARGE_ACTIVE: 19.056.6, P17.2
CHG_LED: P16.2, P17.1
GND: 19.051.1, 19.051.18, 19.051.34, 19.052.10, 19.052.11, 19.052.14, 19.052.15, 19.052.16, 19.052.17, 19.053.10, 19.053.11, 19.053.14, 19.053.16, 19.053.17, 19.054.A1, 19.054.A12, 19.054.B1, 19.054.B12, 19.054.SH, 19.055.2, 19.056.1, 19.056.3, 19.057.2, BT1.2, DISP1.4, P1.2, P2.2, P3.2, P4.2, P5.2, P6.2, P7.2, P8.2, P11.2, P12.2, P13.2, S1.2, S2.2, S3.2, S4.2, S5.2, S6.2, S7.2, S8.2, S9.2, S10.2, S11.2, S12.2, S13.2, S14.2, S15.2, S16.2, S17.2, S18.2, S19.2, S20.2, S21.2, S22.2, S23.2, S24.2, S25.2, S26.2, S27.2, S28.2, _1.2
I2C_RESET: 19.051.13, 19.052.18, 19.053.18, P14.2
I2C_SCL: 19.051.14, 19.052.12, 19.053.12, P9.2
I2C_SDA: 19.051.17, 19.052.13, 19.053.13, P10.2
MCP_A_INT: 19.051.12, 19.052.20
MCP_B_INT: 19.051.9, 19.053.20
NV_CS: 19.051.45, DISP1.5
PROG: 19.056.2, P13.1
RESET: 19.051.28, P15.2, _1.1
SPI_MOSI: 19.051.41, DISP1.1
SPI_SCK: 19.051.44, DISP1.2
USB_CC1: 19.054.A5, P11.1
USB_CC2: 19.054.B5, P12.1
USB_DM: 19.051.36, 19.054.A7, 19.054.B7, 19.055.3, 19.055.4
USB_DP: 19.051.37, 19.054.A6, 19.054.B6, 19.055.1, 19.055.6
VBAT: 19.051.32, 19.056.4, 19.057.1, P3.1, P4.1, T1.2
VBAT_SW: BT1.1, T1.1
VBUS: 19.051.35, 19.054.A4, 19.054.A9, 19.054.B4, 19.054.B9, 19.055.5, 19.056.7, 19.056.8, P1.1, P2.1, P16.1
VCC: 19.052.9, 19.053.9, 19.053.15, 19.057.3, DISP1.3, P5.1, P7.1, P8.1, P9.1, P10.1, P14.1, P15.1
VDD_MCU: 19.051.31, P6.1
sw_matrix_index_bottom: 19.053.7, S19.1
sw_matrix_index_home: 19.053.1, S20.1
sw_matrix_index_mod: 19.053.22, S18.1
sw_matrix_index_num: 19.052.5, S22.1
sw_matrix_index_top: 19.052.23, S21.1
sw_matrix_inner_bottom: 19.053.8, S23.1
sw_matrix_inner_home: 19.053.2, S24.1
sw_matrix_inner_num: 19.052.6, S26.1
sw_matrix_inner_top: 19.052.24, S25.1
sw_matrix_middle_bottom: 19.053.6, S14.1
sw_matrix_middle_home: 19.052.28, S15.1
sw_matrix_middle_mod: 19.053.21, S13.1
sw_matrix_middle_num: 19.052.4, S17.1
sw_matrix_middle_top: 19.052.22, S16.1
sw_matrix_outer_bottom: 19.053.3, S1.1
sw_matrix_outer_home: 19.052.25, S2.1
sw_matrix_outer_num: 19.052.1, S4.1
sw_matrix_outer_top: 19.052.7, S3.1
sw_matrix_pinky_bottom: 19.053.4, S5.1
sw_matrix_pinky_home: 19.052.26, S6.1
sw_matrix_pinky_num: 19.052.2, S8.1
sw_matrix_pinky_top: 19.052.8, S7.1
sw_matrix_ring_bottom: 19.053.5, S9.1
sw_matrix_ring_home: 19.052.27, S10.1
sw_matrix_ring_num: 19.052.3, S12.1
sw_matrix_ring_top: 19.052.21, S11.1
sw_thumbs_layer_cluster: 19.053.23, S27.1
sw_thumbs_space_cluster: 19.053.24, S28.1

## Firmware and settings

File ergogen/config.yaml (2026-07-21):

# Hypothenar - chip-direct PCBA design.
#
# Architecturally different from rc1:
#   - Discrete nRF52840 module (MS88SF3) on the PCB, not a Nice!Nano daughter board.
#   - Diode matrix scanned directly by the MS88SF3 (converted from 2x
#     MCP23017 I/O expanders 2026-07 - the module has plenty of GPIOs).
#   - Switch-per-pin (each key directly wired to a unique GPIO) - no diodes.
#   - One PCB design per half (no reversibility; v1 emits this config twice
#     with mirroring for the right half).
#
# Status: MS88SF3 PAD MAP VALIDATED (2026-07) against the Minew MS88SF3
# rev-K datasheet (Datasheet_K_EN, section 3 Pin Description diagram) -
# every assigned pad (GND 1/18/34, VDD 31, VDDH 32, VBUS 35, D- 36, D+ 37,
# SWDIO 49, SWCLK 50, and GPIOs P9=P0.02, P10=P0.29, P11=P0.28, P12=P0.30,
# P13=P0.31, P14=P0.27, P15=P0.05, P16=P0.04/AIN2, P17=P0.26, P28=P0.18,
# P41=P0.17, P44=P0.20, P45=P0.22) matches the datasheet pad-for-pad.
# NOTE: pad 33=DCCH (DC/DC out) and 51=RF are correctly left NC (module
# handles DC/DC + antenna internally); pads 24/25=P0.00/P0.01 are the
# LFXO pins - the module has no 32.768kHz crystal, so ZMK runs the
# internal RC (fine for BLE). Component positions in the MCU/power zone
# are still first-pass; expect to iterate placement in KiCad.

units:
  kx: cx
  ky: cy
  px: kx+2
  py: ky+2
  # MCU module: MS88SF3 is 12.5 x 18.5 mm (kleeb footprint extents)
  mcu_width: 13
  mcu_height: 19
  # I/O expander: MCP23017 in SOIC-28W is ~10 x 18 mm including pads
  mcp_width: 10
  mcp_height: 19
  # USB-C: ~9 x 7.5 mm
  usbc_width: 10
  usbc_height: 8
  # Power chips smaller: TP4056 5x4, XC6206 4x2.5, USBLC6 3x2
  # General spacing
  mcu_padding: 1.5
  switchplate_switch_cutout: 14
  scrollwheel_width: 17
  scrollwheel_height: 14
  screw_diameter: 4.7
  screw_hole: 4.1

points:
  rotate: 5
  zones:
    # === Matrix: 5 rows x 6 cols, same physical layout as rc1's `thenar/`.
    # Each key gets a unique `switch_net` (not a matrix col_net/row_net) so
    # we can wire each switch to a dedicated MCP23017 GPIO.
    matrix:
      anchor.shift: [50, -150]
      key:
        tags: [switch]
        padding: 1ky
        spread: 1kx
      columns:
        outer:
          rows:
            mod.skip: true
          key:
            column_net: col0     # diode matrix: per-column driver net
        pinky:
          rows:
            mod.skip: true
          key:
            origin: [0, 8]
            column_net: col1
        ring:
          rows:
            mod.skip: true
          key:
            origin: [0, 8]
            stagger: 0.66ky
            splay: -5
            column_net: col2
        middle:
          key:
            stagger: 0.33ky
            column_net: col3
        index:
          key:
            stagger: -0.33ky
            column_net: col4
        inner:
          rows:
            mod.skip: true
          key:
            stagger: -2.5
            column_net: col5
      rows:
        # The `row_net` ergogen assigns to each row would normally be the
        # column-driver wire. In switch-per-pin we override per-key with
        # a unique net via the `from`/`to` params on the choc footprint -
        # see the pcbs.footprints section below.
        mod:    { row_net: __mod__,    tags: [switch_bottom] }
        bottom: { row_net: __bottom__, tags: [switch_top] }
        home:   { row_net: __home__,   tags: [switch_bottom] }
        top:    { row_net: __top__,    tags: [switch_top] }
        num:    { row_net: __num__,    tags: [switch_bottom] }

    # === Thumb cluster
    thumbs:
      anchor:
        ref: matrix_middle_home
        shift: [38, -44]
      key:
        tags: [switch]
        padding: 1ky
        spread: 1kx
      columns:
        layer:
          key:
            splay: -15
            column_net: col3    # diode matrix: __thumb__ row x col3
            tags: [switch_bottom]   # so it gets a diode (diode_bottom)
        space:
          key:
            width: 1.5kx
            splay: 75
            shift: [13-kx, -3]
            column_net: col4    # diode matrix: __thumb__ row x col4
            tags: [switch_space]
      rows:
        cluster:
          row_net: __thumb__

    # === Scrollwheel encoder (EVQWGD001)
    scrollwheel:
      anchor:
        ref: matrix_inner_bottom
      columns:
        scrollwheel:
          key:
            tags: [scrollwheel]
            # Positioned/angled by hand in KiCad (2026-07) and encoded back
            # here: nudged ~6.2mm toward the thumb cluster and splayed -15
            # to match the thumb `layer` key, so the wheel sits naturally
            # under the thumb instead of square to the grid.
            shift: [kx+mcu_padding-1.25+0.43, -6.24]
            rotate: -15
            column_net: GND
            width: scrollwheel_width
            height: scrollwheel_height
      rows:
        scrollwheel:
          row_net: __scroll__
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

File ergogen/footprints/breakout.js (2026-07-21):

// Debug + expansion breakout header.
//
// Breaks out SWD (SWDIO/SWCLK/RST), power (3V3/GND/VBAT), and ALL free
// nRF52840 GPIOs to a 2x20 (40-pin) 2.54 mm through-hole header. The key
// matrix lives entirely on the I2C expanders, so ~34 MCU GPIOs are spare;
// this exposes every one for future peripherals (I2C/SPI/UART/PWM are
// mappable to any pin in firmware; P0.03 is the one free AIN/analog pin).
//
// Net defaults match the GP_<port>_<pin> nets the MS88SF3 free pads carry
// in config.yaml (+ SWDIO/SWCLK/RESET/VCC/GND/VBAT), so it auto-connects
// with no per-net wiring in the config - just place it.
//
// This is a "start Max, trim in KiCad" footprint: delete pads/rows you
// don't need and shrink it once you see the routing/space. Hand-soldered
// (or leave unpopulated as test pads), so not part of PCBA placement.
//
// Pin order (col-major, 2 rows): pad 1=SWDIO, 2=SWCLK, 3=RST, 4=3V3,
// 5=GND, 6=VBAT, then the free GPIOs.

const PINS = [
  ['SWDIO', 'SWDIO'], ['SWCLK', 'SWCLK'], ['RST', 'RESET'],
  ['3V3', 'VCC'], ['GND', 'GND'], ['VBAT', 'VBAT'],
  // (P0.03/06/07/08/09/10/11/13 moved to the diode matrix + encoder btn)
  ['P0.14', 'GP_P0_14'], ['P0.15', 'GP_P0_15'], ['P0.16', 'GP_P0_16'],
  ['P0.19', 'GP_P0_19'], ['P0.21', 'GP_P0_21'], ['P0.23', 'GP_P0_23'],
  ['P0.24', 'GP_P0_24'], ['P0.25', 'GP_P0_25'], ['P0.00', 'GP_P0_00'],
  ['P0.01', 'GP_P0_01'],
  ['P1.00', 'GP_P1_00'], ['P1.01', 'GP_P1_01'], ['P1.02', 'GP_P1_02'],
  ['P1.03', 'GP_P1_03'], ['P1.04', 'GP_P1_04'], ['P1.05', 'GP_P1_05'],
  ['P1.06', 'GP_P1_06'], ['P1.07', 'GP_P1_07'], ['P1.08', 'GP_P1_08'],
  ['P1.09', 'GP_P1_09'], ['P1.10', 'GP_P1_10'], ['P1.11', 'GP_P1_11'],
  ['P1.12', 'GP_P1_12'], ['P1.13', 'GP_P1_13'], ['P1.14', 'GP_P1_14'],
  ['P1.15', 'GP_P1_15'],
];

const PITCH = 2.54;

const params = { designator: 'J', side: 'F' };
PINS.forEach((pin, i) => {
  params['n' + i] = { type: 'net', value: pin[1] };
});

module.exports = {
  params,
  body: p => {
    let pads = '';
    PINS.forEach((pin, i) => {
      const col = Math.floor(i / 2);
      const row = i % 2;
      const x = (col * PITCH).toFixed(3);
      const y = (row * PITCH).toFixed(3);
      const net = p['n' + i];
      // labels: row 0 above, row 1 below, so text doesn't collide
      const ly = (row === 0 ? Number(y) - 1.5 : Number(y) + 1.5).toFixed(3);
      pads += `
    (pad ${i + 1} thru_hole circle (at ${x} ${y} ${p.rot}) (size 1.7 1.7) (drill 1.0)
      (layers *.Cu *.Mask) ${net.str})
    (fp_text user "${pin[0]}" (at ${x} ${ly} ${p.rot}) (layer ${p.side}.SilkS)
      (effects (font (size 0.5 0.5) (thickness 0.08))))`;
    });
    return `
    (module breakout_header (layer F.Cu) (tedit 0)
    ${p.at}
    (descr "Debug + expansion breakout: SWD + power + all free nRF GPIOs, 2x20 2.54mm")
    (tags "breakout debug swd expansion header")
    (fp_text reference "${p.ref}" (at 0 -2.6) (layer ${p.side}.SilkS) ${p.ref_hide}
      (effects (font (size 0.7 0.7) (thickness 0.1))))
    (fp_text value "BREAKOUT" (at 0 5.1) (layer ${p.side}.Fab) hide
      (effects (font (size 0.7 0.7) (thickness 0.1))))
    ${/* pin-1 square marker */ ''}
    (fp_line (start -1.5 -1.5) (end -1.5 1.5) (layer ${p.side}.SilkS) (width 0.12))
    ${pads}
    )
  `;
  },
};

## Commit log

2026-07-06 feat: hypothenar - pick-and-place split keyboard, extracted from thenar
    Hypothenar (the pinky-side palm muscle pad) is the JLCPCB-assembled
    sibling of the hand-soldered thenar keyboard
    (github.com/lytedev/thenar-keyboard). Same physical layout - 58
    positions, thumb cluster, EVQWGD001 scrollwheel - completely different
    electronics:
    - MS88SF3 nRF52840 module soldered to the PCB (thenar: socketed
    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
    [designguide-schematic.kicad_pcb, designguide-schematic.kicad_sch, hypothenar-left.kicad_pcb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]
2026-07-07 feat(pcb): verified MS88SF3 pad map + electronics bay placement + NPTH holes
    Three independent hardware-scaffold fixes:
    1. MS88SF3 pad map VERIFIED against the Minew datasheet (rev K,
    store.minewsemi.com/wp-content/uploads/2024/03/MS88SF3-nRF52840_Datasheet_K_EN.pdf).
    Replaces the placeholder assignments. Key corrections:
    - USB D+/D- are dedicated pads 37/36, not GPIOs
    - Power is high-voltage mode: battery -> VDDH (pad 32); VDD
    (pad 31) is the internal regulator OUTPUT (REGOUT0=3.3V via the
    nice_nano_v2 bootloader) - decouple only, never tie to the LDO
    rail
    - Concrete GPIO picks: I2C SDA/SCL = P0.26/P0.27, I2C reset =
    P0.31, encoder = P0.29/P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
    [config.yaml]
2026-07-07 fix(zmk): firmware builds green for both halves against zmk v0.3.0
    Both UF2s now build: left 334KB / right 323KB (BLE + USB HID central,
    BLE peripheral, MCP230XX expander driver, EC11-ready). The skeleton
    had never compiled; fixes in dependency order:
    1. west.yml: pin zmk v0.3.0 (was main - same trap as thenar: a
    main snapshot pulls Zephyr 4.1 whose hardware-model-v2 rejects
    this board layout outright). flake zephyrDepsHash matches -
    identical snapshot to the thenar repo, so it was already cached.
    2. pinctrl: drop nonexistent nordic/nrf52840_qiaa-pinctrl.dtsi
    include; datasheet-verified pins (I2C P0.26/P0.27, SPI
    P0.20/P0.17/MISO parked on P0.24, see the pcb com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
2026-07-07 feat: wire MCP23017 interrupt lines for wake-on-keychange
    Power-budget analysis flagged the biggest battery-life risk in the
    switch-per-pin design: zmk,kscan-gpio-direct reads the expanders over
    I2C, and without interrupt lines that means continuous polling - the
    MCU never sleeps between keys, plausibly costing mA-scale average
    draw (weeks of battery instead of months on the 110mAh cell).
    The Zephyr 3.5 mcp23xxx driver has full int-gpios support (verified
    in the pinned deps: binding property + ISR + INTCAP acknowledge), so
    these are immediately functional, not just routing insurance:
    - MCU pad 12 (P0.30) -> MCP_A_INT -> mcp_a INTA
    - MCU pad 9 (P0.02) -> MCP_B_INT -> mcp_b INTA
    - One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
    [config.yaml, mcp23017.js]
2026-07-07 docs+power: cited battery-life estimate; enable ZMK deep sleep
    docs/power-budget.md: analytical power budget for the 110mAh cell,
    every term sourced (Nordic/Microchip/Torex datasheets, ZMK power
    profiler for the BLE-idle community baseline). Headline numbers:
    ~2-3.5 months interrupt-driven scanning + deep sleep (our design)
    ~6 weeks if deep sleep stays off
    ~9-14 days if scanning degrades to I2C polling (the scenario
    the INTA traces exist to prevent)
    The weeks-vs-months gap doubles as the no-equipment validation
    method: battery telemetry over a week of use distinguishes the two
    regimes without a bench power profiler.
    zmk/hypothenar.conf: CONFIG_ZMK_SLEEP=y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
2026-07-07 docs(power): add realistic 8h/day usage scenario
    Answering 'what about 8hrs daily usage': ~1.3mAh/day = the same
    ~2.5-3 months, because typing only adds ~50-150uA during actual
    keystrokes (connected-idle already pays the BLE keep-alive tax) and
    the extra deep-sleep hours of a real workday cancel it. Battery life
    is governed by hours-connected, not keystrokes.
2026-07-07 docs(power): mark deep-sleep action done (was enabled in eb336a45)
2026-07-07 feat(pcb): decoupling caps, resistors, charge LED, battery pads
    18 machine-placeable components the scaffold was missing - on this
    board they must come from ergogen (JLCPCB places them), not manual
    KiCad additions:
    C1-C8: bulk + local decoupling per the build recipe / Nordic
    reference (VBUS, VBAT, VCC, VDD_MCU rails; 100nF within reach of
    each IC's supply pin)
    R1/R2 4.7k I2C pull-ups, R3/R4 5.1k USB-C CC pull-downs (UFP role),
    R5 12k TP4056 PROG (~100mA charge), R6/R7 100k reset pull-ups,
    R8 1k + D1 0603 LED charge indicator (VBUS->LED->CHRG)
    BT1: battery terminal pads (2mm PTH, VBAT_SW/GND) - the VBAT_SW net
    previously terminated NOWHERE; the battery had no connec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
    [config.yaml]
2026-07-07 feat(route): port the freerouting pipeline from thenar
    .#routed-auto autoroutes the scaffold (freerouting v2.2.4 direct
    fetch - nixpkgs 2.2.1 NPEs; kicad-python wrapper for pcbnew; the
    DSN-export/SES-import script with its segfault and GND-plane
    workarounds). The scaffold step now also adds unfilled F/B GND zones
    (patch_keyboard_pcb.py) so ground returns come mostly free at gerber
    fill time.
    Flow (rc1-proven hybrid):
    nix build .#routed-auto # ~25min, expect ~90-95% completion
    cp result/keyboard.kicad_pcb routed/keyboard-left.kicad_pcb
    # hand-finish in KiCad: USB diff pair, power tree, leftovers
2026-07-07 feat(route): freerouting baseline for the left half
    nix build .#routed-auto output (50 passes): 1094 segments, 158 vias,
    9 unconnected items remaining out of ~90 nets (~95%):
    - 5x GND (intentional - the DSN strips GND planes so freerouting
    doesn't fight them; the F/B zones fill at gerber time and the
    remaining stubs get absorbed or hand-tied)
    - USB_DM one leg (hand-route the D+/D- pair tightly anyway,
    per docs/build-recipe.md Stage 4a)
    - sw_thumbs_layer_cluster, sw_matrix_outer_bottom,
    sw_matrix_pinky_bottom
    This is the hand-finishing STARTING POINT, not a fab candidate:
    rip and redo the USB pair + power tree, connect the leftovers,
    then DRC to clean before gerbers.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
    [keyboard-left.kicad_pcb]
2026-07-07 feat(pcb)!: all electronics to the bottom side; bay shrinks to a lip
    Daniel's call: the top-edge electronics bay was a wart. All ICs and
    passives move to B.Cu, tucked along the inner edge under/next to the
    key area; the outline reverts to the organic keyboard shape plus a
    34mm lip (1.3-3.8mm proud) for USB-C + antenna keepout and a small
    display wing. Board area -10%, bbox 6mm shorter.
    Wrapper work this required: the kicad_mod converter and all
    hand-written SMD wrappers now emit properly MIRRORED geometry for
    side: B (pad x, arcs, silk, pin-1 markers, justify mirror on text) -
    previously only layer names swapped, which would have fabbed
    garbage. Net interfaces unchanged.
    Placement notes: S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
    [config.yaml, mcp23017.js]
2026-07-07 feat(route): fresh freerouting baseline for the bottom-side layout
    Supersedes the bay-era baseline: 1231 segments, 167 vias, 8
    unconnected items (~95%) on the compact placement. Same finishing
    list as before: USB D+/- pair by hand, power tree at 0.4mm, tie off
    the GND stubs and leftover switch nets, DRC clean before gerbers.
    [keyboard-left.kicad_pcb]
2026-07-07 feat(pcb): charge LED to the top side above the encoder
    Daniel's request during the interactive placement session: D1 moves
    to F.Cu above the scrollwheel where it's actually visible (it was
    facing the case floor). R8 stays on the bottom with the power
    cluster.
2026-07-07 feat(pcb): flatten the top outline - hump removed
    USB-C moves to the inner (right) edge below reset (mouth +x, ~0.7mm
    proud); MS88SF3 rotates -8.12deg to ride the natural sloped top edge
    with its antenna courtyard verified fully off-board (25-point sample);
    nice!view drops from the wing to the inner strip (glass hovers over
    the B-side USB/slider zone, header 3mm above the encoder); MCP#1 +
    passives follow. Outline loses the lip+wing band entirely: area
    -3.7%, bbox height 122.8 -> 111.1mm. Also fixes a latent anchor trap
    (io_expander_2 followed MCP#1) and two R1/R2 clearance regressions
    caught during iteration. DRC: zero courtyard overlaps, no new classes.
    Note: routed/keyboard-left.kicad_pc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
    [config.yaml]
2026-07-07 feat(route): autoroute baseline for the flattened outline
    Replaces the stale pre-flatten baseline. Hand-finish list unchanged:
    USB D+/- pair, power tree at 0.4mm, GND stubs + leftover switch nets,
    DRC clean before gerbers.
    [keyboard-left.kicad_pcb]
2026-07-08 docs: fix Choc hotswap socket LCSC part number
    C2913963 returns zero results on LCSC (wrong or delisted - caught at
    order time). Correct part: Kailh CPG135001S30 = LCSC C5333465,
    verified live (~$0.074/pc):
    https://www.lcsc.com/product-detail/Mechanical-Keyboard-Shaft_Kailh-CPG135001S30_C5333465.html
2026-07-19 fix(pcb): pre-order validation - divider resistors, netlist ERC, order gate
    Pre-PCBA validation pass (netlist ERC cross-read + kicad-cli DRC + BOM).
    This board is a non-reworkable JLCPCB PnP run with no schematic/ERC, so
    the ergogen nets are the only netlist - validated them as the missing
    ERC. Verdict: NOT ready to order; see docs/pre-order-checklist.md.
    Fixed here (pad-map-independent, safe now):
    - Battery-sense divider resistors added: R9 (820k, VBAT->BATT_ADC) +
    R10 (2.0M, BATT_ADC->BATT_ADC_EN), matching the firmware divider
    (output-ohms=2.0M, full-ohms=2.82M). BATT_ADC was a FLOATING single-
    pad net - the battery gauge (and the whole interrupt-vs-polling
    battery-life validatio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
    [config.yaml]
2026-07-19 docs(pcb): MS88SF3 pad map datasheet-verified - gate #1 cleared
    Cross-checked every assigned MS88SF3 pad against the Minew MS88SF3 rev-K
    datasheet (Datasheet_K_EN, section 3 Pin Description pad diagram). ALL
    correct pad-for-pad: GND 1/18/34, VDD 31, VDDH 32, VBUS 35, D- 36, D+ 37,
    SWDIO 49, SWCLK 50, and every GPIO (P9=P0.02, P10=P0.29, P11=P0.28,
    P12=P0.30, P13=P0.31, P14=P0.27, P15=P0.05, P16=P0.04/AIN2, P17=P0.26,
    P28=P0.18, P41=P0.17, P44=P0.20, P45=P0.22). The config's own 'NOT
    VALIDATED' status is now cleared - this was the foundational gate every
    other net rested on.
    - config.yaml + hypothenar.dts: status/comments updated to VALIDATED,
    with the datasheet reference and the pad list.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
    [config.yaml]
2026-07-19 feat(pcb): debug + expansion breakout - SWD + power + all 34 free GPIOs
    Fixes the unprogrammable-brick blocker (SWDIO/SWCLK were dead-end nets,
    no programming footprint) AND adds the expansion breakout the user asked
    for. The matrix is entirely on the I2C expanders, so ~34 nRF52840 GPIOs
    are spare - this breaks out every one, plus SWD and power.
    - ergogen/footprints/breakout.js: new parametric 2x20 (40-pin) 2.54mm
    through-hole header. Pin order: SWDIO/SWCLK/RST/3V3/GND/VBAT then the
    34 free GPIOs (P0.03=AIN is the one free analog). Net defaults match
    the GP_<port>_<pin> nets on the MS88SF3 free pads, so it auto-connects
    with no per-net wiring. Silk-labelled per pad; pin-1 marker.
    -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
    [breakout.js, config.yaml]
2026-07-21 feat(pcb)!: convert switch scan from I2C expanders to a diode matrix
    The MS88SF3 breaks out ~47 GPIOs and the matrix was the only big
    consumer, so the 2x MCP23017 per half were solving a pin-scarcity
    problem that doesn't exist. A diode matrix is cheaper (Basic diodes vs
    Extended-tier ICs + ~2 setup fees), simpler (no I2C bus / pull-ups /
    addresses / interrupt lines), and removes the interrupt-vs-polling
    power risk entirely (no bus to poll). Stays single-sided PnP - diodes
    go bottom-side with the rest.
    ergogen:
    - switches: from sw-per-MCP-pin to a real diode matrix. choc footprint
    now ; new footprint carries
    {{colrow}}->{{row_net}} (col2row), ported from the thenar. Columns
    outer/pink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
    [breakout.js, config.yaml]
2026-07-21 docs: pre-order checklist - diode-matrix architecture change + firmware task
    Adds the architecture-change banner: I2C expanders -> diode matrix
    (ergogen done/validated). Flags that both halves are now a fresh route
    from the new scaffold, adds the firmware kscan-gpio-matrix conversion as
    a new blocker with the full row/col/encoder pin map, and notes the BOM
    swap (drop 2x MCP23017 + I2C passives, add 28 diodes/half; net savings).
2026-07-21 feat(firmware): convert ZMK kscan from I2C expanders to the diode matrix
    Matches the ergogen diode-matrix conversion. Builds clean both halves
    (nix build .#firmware -> zmk_left.uf2 + zmk_right.uf2).
    - hypothenar.dts: removed the i2c0 node + both mcp23017 children.
    - hypothenar.dtsi: replaced the kscan-gpio-direct placeholder with a
    zmk,kscan-gpio-matrix (diode-direction col2row) on the datasheet-
    verified pins - rows P0.26/27/31/30/02/03, cols P0.06-0.11. New 6x12
    matrix transform, laid out to keep the existing interleaved 56-position
    keymap unchanged. Fixed the encoder: quadrature back on MCU P0.29/P0.28
    (was wrongly on mcp_b 4/5 - the pre-order-review bug).
    - overlays: both poin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
2026-07-21 feat(pcb): per-orientation diode placement (ported from thenar)
    Replaces the single naive diode entry (all 28 at one offset) with the
    thenar proven per-switch-orientation placement: diode_bottom shift
    [0,-9.5], diode_top [0,5.2], diode_space rotate -90 shift [8.275,1].
    Tagged the thumb layer key switch_bottom so it still gets a diode.
    Verified: ergogen regenerates, exactly 28 ComboDiodes for 28 sockets
    (no doubles/misses). Gives the autorouter a sane starting placement.
    [config.yaml]
2026-07-21 feat(pcb): place breakout header in the open band below the grid
    Moved the debug/expansion breakout off its top-right placeholder (it
    overlapped the MCU) into the open horizontal strip below the switch
    grid, clear of sockets/diodes. Verified by rendering the board. Gives
    the autorouter a sane full placement. Trim/relocate freely in KiCad.
2026-07-21 fix(pcb): EVQWGD001 locating-peg hole (no more flush-cutting the pin)
    The encoder has a plastic locating peg that had to be FLUSH-CUT to seat
    the part on the thenar. Added the NPTH so it drops through and actually
    locates the wheel.
    Position is authoritative, from the vendored
    lib/kleeb/switch.pretty/EVQWGD001.kicad_mod (its pad coords match ours
    exactly): NPTH at (-5.625, +6.3), drill 1.5mm - the peg sits on the
    opposite end of the body from the two button pins.
    This REPLACES the duplicate S1/S2 pair that sat at y=+6.2. That pair
    existed only so one REVERSIBLE PCB could be populated from either face
    (what the thenar does - same board flipped per half, which is why its
    underside silk reads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
2026-07-21 fix(pcb): real reference designators (were mangled by an ergogen unit collision)
    Every IC came out as 19.051..19.055, the reset as _1, screw holes as
    _2.._5, and the encoder as REF**. Junk designators break JLCPCB PCBA,
    which matches the BOM to the CPL BY DESIGNATOR - so this was a
    pre-order blocker, not just a readability annoyance.
    Root cause: the footprints declared designator "U" (correct for ICs),
    but ergogen evaluates that against its built-in unit U = 19.05mm (one
    keyboard unit). So the prefix rendered as 19.05 and the counter
    appended: 19.051..19.055. Confirmed by swapping one to IC and getting
    IC1. Nothing wrong with the footprints - just an unfortunate name
    collision.
    Since U is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
2026-07-21 feat(pcb): angle the scrollwheel to the thumb cluster + PWR silk label
    Encoder placed by hand in KiCad and encoded back into ergogen so it
    survives regeneration: nudged ~6.2mm toward the thumb cluster and
    splayed -15deg to match the thumb layer key, so the wheel sits under
    the thumb instead of square to the grid. Verified the ergogen output
    reproduces the hand placement to within 0.001mm (169.751/-122.527/-15).
    Also: the power slider had NO silk label (only an outline) while the
    reset button prints RESET on both faces - added a PWR label below the
    pin row, mirrored on B.SilkS so it reads from either side.
    KNOWN ISSUE (pre-existing, not from this move): the board outline does
    not follow the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
    [config.yaml]
2026-07-21 fix(pcb): USBLC6 pads were shorted; clear R9/R10 + breakout collisions
    USBLC6 (SOT-23-6) pads were 0.6 x 1.2mm on a 0.95mm pitch - 1.2mm tall
    pads on a 0.95mm pitch OVERLAP by 0.25mm, physically merging pins 1-2-3
    and 4-5-6. That shorted USB_DP, GND, USB_DM and VBUS together: a dead
    VBUS-to-GND short on the USB port. Width/height were transposed; a
    SOT-23-6 land pattern needs the long axis running outward from the body,
    so (size 0.6 1.2) -> (size 1.2 0.6). Now 0.35mm gap between pads.
    This also corrects an earlier misdiagnosis: the four shorts the routed-
    board DRC reported (USB_DP/GND, GND/USB_DM, USB_DM/VBUS, VBUS/USB_DP)
    were blamed on freerouting running traces too close to the connecto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
    [config.yaml]
2026-07-21 docs: record the hand-solder-heritage footprint issues as a PnP blocker
    Adds checklist item 4: these footprints came from the thenar (hand-
    soldered, reversible) and were never adapted for a single-sided
    pick-and-place run. Records the USBLC6 short (fixed), the diodes
    landing on the front (ComboDiode has no side param and emits pads on
    both faces plus THT - would force double-sided assembly), and the CPL
    side-reporting bug (module layer hardcoded F.Cu even when side: B puts
    the pads on B.Cu, so JLC would place bottom parts on top).
2026-07-21 feat(pcb): encode the hand re-layout of the MCU/power corner into ergogen
    All 20 components repositioned by hand in KiCad and encoded back into
    ergogen so they survive regeneration. Verified: every part reproduces
    the hand placement to within 0.15mm.
    Key change: the MS88SF3 is rotated -8.122 -> -99.7 and relocated, so its
    antenna is aimed off-board at open space TOWARD THE OTHER HALF rather
    than along the sloped top edge. That should help the inter-half BLE link
    - the same weak-split-link problem that made the thenar laggy and
    out-of-order until the +8dBm TX bump.
    Broke the anchor dependency chains (ldo->charge_ic, esd->usb_c,
    reset->slider) by re-anchoring those zones directly to matrix_i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
    [config.yaml]
2026-07-21 feat(pcb): trim the right board edge 6mm after the layout compaction
    The outline is an explicit polygon of matrix point references, so it
    never followed the components - the 39.5mm right-edge offset was sized
    for the OLD sprawling power cluster. After compacting that corner the
    rightmost extent is ~183mm (MS88SF3 body) against an edge at 190.57mm,
    so ~7.5mm was dead space.
    Pulled the two right-edge reference points 39.5 -> 33.5, leaving ~1.5mm
    clearance to the module body. DRC still reports zero shorting_items.
    Remaining edge-clearance violations are by design or pre-existing: J2s
    shield deliberately overhangs (USB-C mouth plugs in from outside), ENC1s
    segments ARE its own Edge.Cuts wheel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
    [config.yaml]
